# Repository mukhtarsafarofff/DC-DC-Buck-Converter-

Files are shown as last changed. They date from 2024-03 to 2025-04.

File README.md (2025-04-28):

(ENG)   A Constant Current (CC), and Constant Voltage (CV) converter can come in very handy in various conditions, for example, if you want to charge a lithium battery with a constant current you can do that very easily with this module. Furthermore, if we are testing a circuit and powering it for the first time it's always recommended to use a constant current that will limit damage to your circuit if you made any mistakes in the build process.I have two 10K potentiometers that are used to set the constant current and voltage level. Furthermore, there are three LED indicators on the board; the first one near the input connector shows when the module is in constant current mode, while the other two near the output are mainly for battery charging applications (battery charging and battery full indicators). Other than that, this IC has an input voltage range of 8V to 36V, and the output voltage of the device is 1.25V to 32V.   With max load, the PWM of the device can reach 100% duty cycle and it can operate on a 180 kHz operating frequency. The constant output current of the module is 5A and it can reach up to 96% efficiency while working. If we are talking about protection features it has thermal shutdown, short circuit protection, and current limit functionality. The main component in this board is the XL4015 buck converter IC, that is a 5pin IC designed. In the schematic we have a 78L05 Voltage Regulator which is an ultra-low-power regulator that is used to convert the input voltage to a constant 5V for the TL431 IC. The TL431 is a reference that is set to a constant current regulator mode with the help of a 71.5K resistor and a potentiometer. This reference is compared to the sense voltage from the output side of the resistor to limit the current. The circuit shown below is the TL431 circuit that is providing a constant current source to the op-amps. When the battery is fully charged, the output goes low so the charging complete LED turns on, now if a battery is charging, the other LED turns on to indicate the battery is charging. To start the test, first of all,i have connected  the buck converter module to the power supply and connect the output to the DC load, and I have set a constant load of 1A to test the circuit.

(DEU)   Ein Konstantstrom (CC)- und Konstantspannungs (CV)-Wandler können in verschiedenen Situationen äußerst nützlich sein. Wenn Sie beispielsweise eine Lithiumbatterie mit einem konstanten Strom laden möchten, können Sie dies mit diesem Modul sehr einfach tun. Darüber hinaus wird empfohlen, bei der ersten Inbetriebnahme einer Schaltung immer einen konstanten Strom zu verwenden, um Schäden an Ihrer Schaltung zu begrenzen, falls Sie während des Aufbauprozesses Fehler gemacht haben.Ich habe zwei 10K-Potentiometer, die verwendet werden, um den konstanten Strom- und Spannungspegel einzustellen. Darüber hinaus gibt es drei LED-Anzeigen auf der Platine; die erste in der Nähe des Eingangsanschlusses zeigt an, wenn das Modul im Konstantstrommodus ist, während die anderen beiden in der Nähe des Ausgangs hauptsächlich für Batterieladeanwendungen sind (Batterielade- und Batterievollanzeige). Abgesehen davon hat dieser IC einen Eingangsspannungsbereich von 8V bis 36V, und die Ausgangsspannung des Geräts beträgt 1,25V bis 32V. Bei maximaler Belastung kann das PWM des Geräts eine Tastverhältnis von 100% erreichen und es kann bei einer Betriebsfrequenz von 180 kHz arbeiten. Der konstante Ausgangsstrom des Moduls beträgt 5A und es kann bis zu 96% Effizienz erreichen, während es arbeitet. Wenn wir über Schutzfunktionen sprechen, verfügt es über thermischen Überlastschutz, Kurzschlussschutz und Funktion zur Strombegrenzung.Das Hauptkomponente auf dieser Platine ist der XL4015-Buck-Wandler-IC, ein 5-poliger IC, der entworfen wurde.Wenn wir über Schutzfunktionen sprechen, verfügt es über thermischen Überlastschutz, Kurzschlussschutz und Funktion zur Strombegrenzung. Die Hauptkomponente auf dieser Platine ist der XL4015-Buck-Wandler-IC, ein 5-poliger IC, der entworfen wurde. Im Schaltbild haben wir einen 78L05-Spannungsregler, der ein ultra-niedriger Leistungsregler ist, der verwendet wird, um die Eingangsspannung auf konstante 5V für den TL431-IC umzuwandeln. Der TL431 ist eine Referenz, die mit Hilfe eines 71,5K-Widerstands und eines Potentiometers auf den konstanten Stromreglermodus eingestellt ist. Diese Referenz wird mit der Sensorspannung von der Ausgangsseite des Widerstands verglichen, um den Strom zu begrenzen.  Die Schaltung unten ist die TL431-Schaltung, die eine konstante Stromquelle für die Operationsverstärker bereitstellt. Wenn die Batterie vollständig aufgeladen ist, wird der Ausgang niedrig, sodass die Lade-LED aufleuchtet. Wenn eine Batterie geladen wird, leuchtet die andere LED auf, um anzuzeigen, dass die Batterie geladen wird.  Ich habe zunächst das Buck-Wandler-Modul an die Stromversorgung angeschlossen und den Ausgang an die Gleichstromlast angeschlossen.

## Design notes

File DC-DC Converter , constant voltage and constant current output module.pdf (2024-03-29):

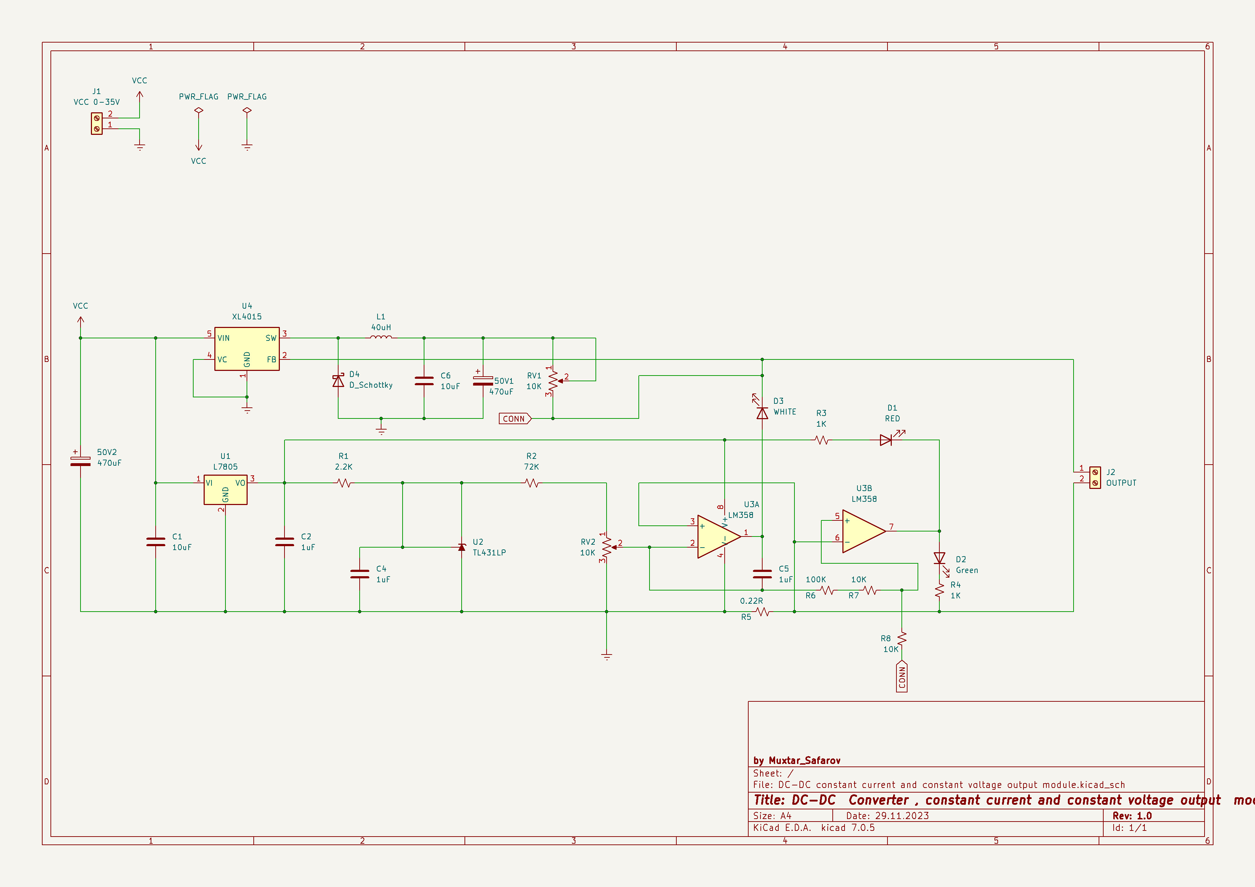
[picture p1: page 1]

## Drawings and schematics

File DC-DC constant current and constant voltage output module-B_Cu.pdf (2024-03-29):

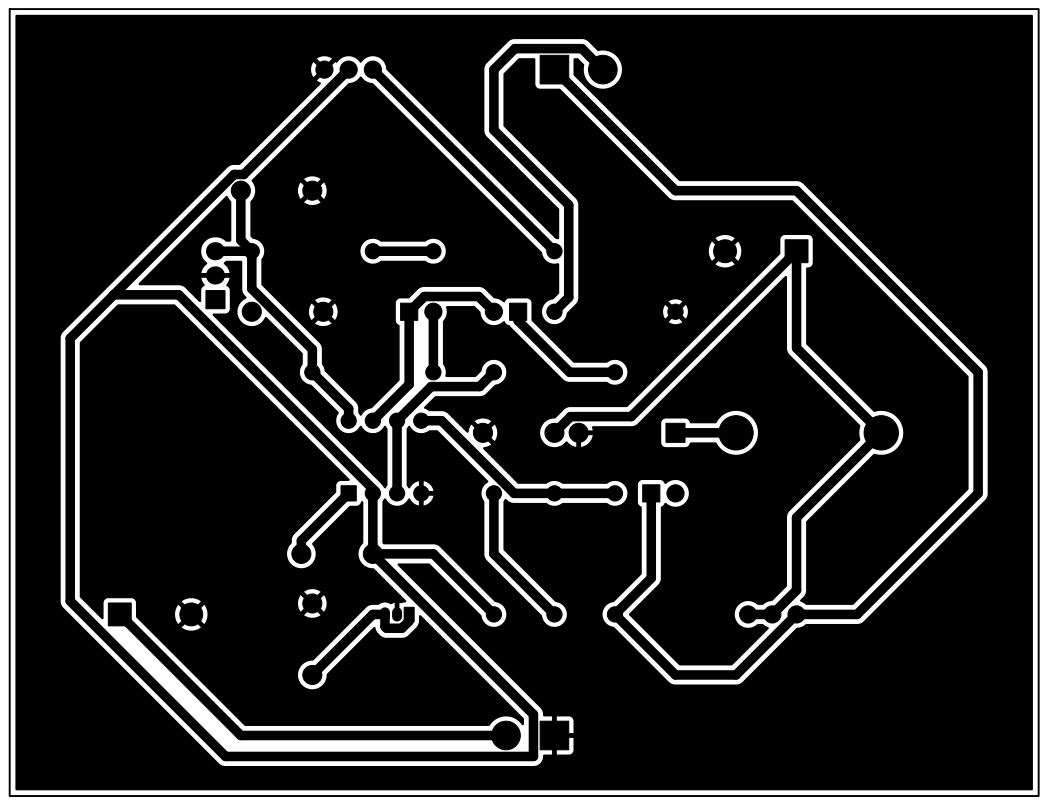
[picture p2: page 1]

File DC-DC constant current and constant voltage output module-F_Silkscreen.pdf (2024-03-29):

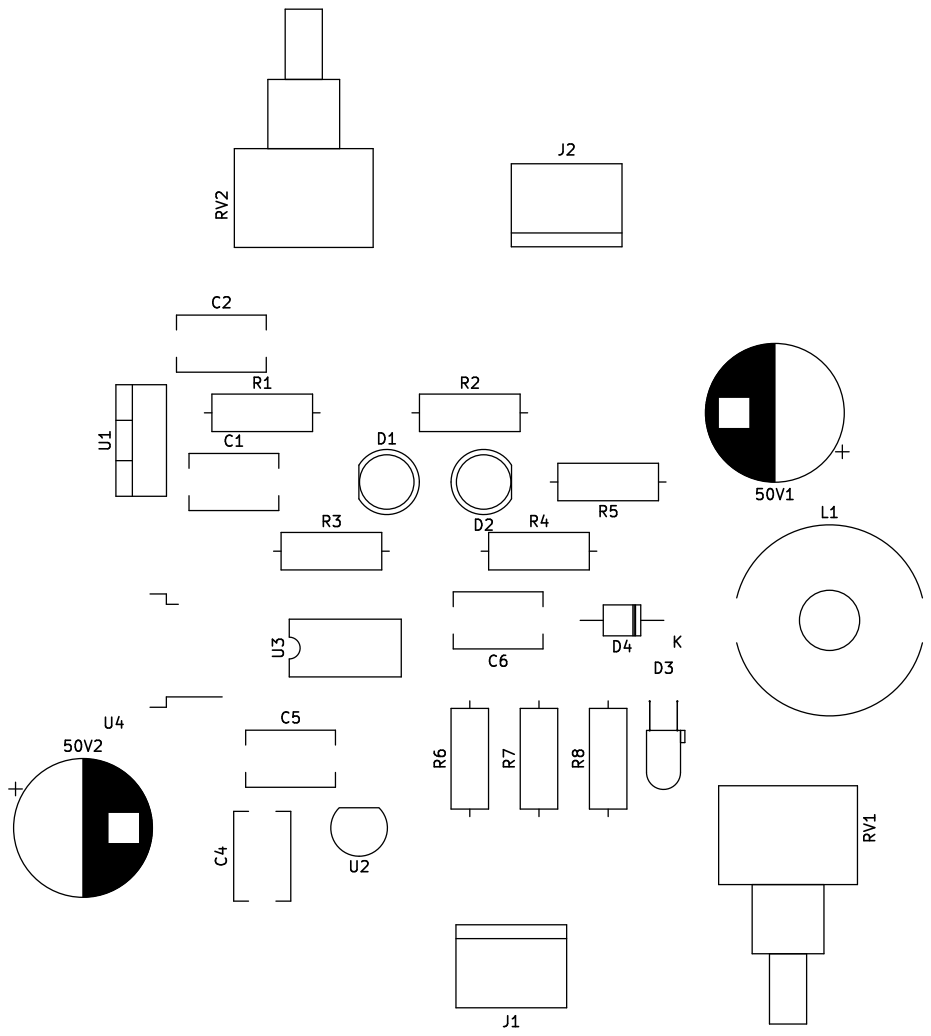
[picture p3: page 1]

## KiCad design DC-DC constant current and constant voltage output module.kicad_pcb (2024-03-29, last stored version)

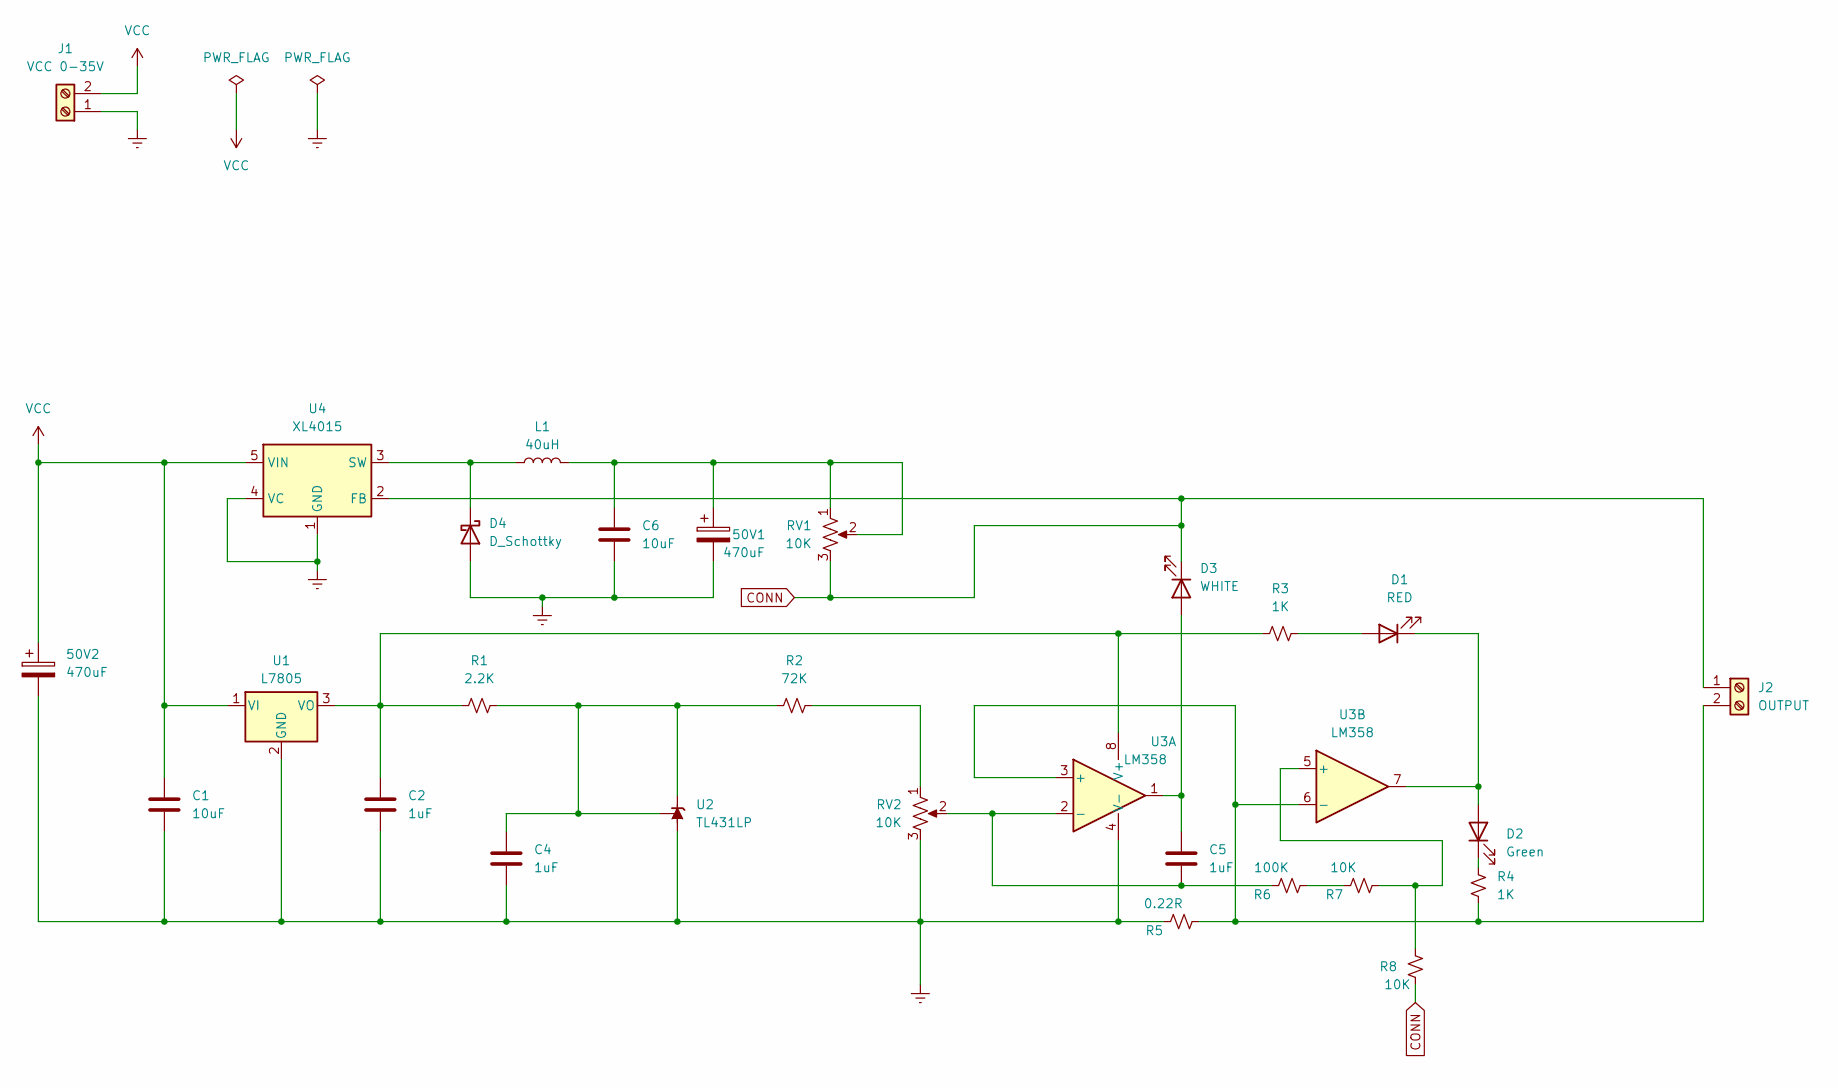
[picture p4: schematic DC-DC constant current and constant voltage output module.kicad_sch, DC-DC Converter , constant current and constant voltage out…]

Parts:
50V1, 50V2: 470uF; CP_Radial_D12.5mm_P7.50mm
C1, C6: 10uF; C_Disc_D8.0mm_W5.0mm_P7.50mm
C2, C4, C5: 1uF; C_Disc_D8.0mm_W5.0mm_P7.50mm
D1: RED; LED_D5.0mm
D2: Green; LED_D5.0mm_Clear
D3: WHITE; LED_D3.0mm_Horizontal_O3.81mm_Z6.0mm
D4: D_Schottky; D_T-1_P10.16mm_Horizontal
J1: VCC 0-35V; TerminalBlock_bornier-2_P5.08mm
J2: OUTPUT; TerminalBlock_bornier-2_P5.08mm
L1: 40uH; L_Toroid_Horizontal_D17.3mm_P15.24mm_Bourns_2000
R1: 2.2K; R_Axial_DIN0309_L9.0mm_D3.2mm_P12.70mm_Horizontal
R2: 72K; R_Axial_DIN0309_L9.0mm_D3.2mm_P12.70mm_Horizontal
R3, R4: 1K; R_Axial_DIN0309_L9.0mm_D3.2mm_P12.70mm_Horizontal
R5: 0.22R; R_Axial_DIN0309_L9.0mm_D3.2mm_P12.70mm_Horizontal
R6: 100K; R_Axial_DIN0309_L9.0mm_D3.2mm_P12.70mm_Horizontal
R7, R8: 10K; R_Axial_DIN0309_L9.0mm_D3.2mm_P12.70mm_Horizontal
RV1, RV2: 10K; Potentiometer_Vishay_148-149_Single_Horizontal
U1: L7805; TO-220-3_Vertical
U2: TL431LP; TO-92_Inline
U3: LM358; DIP-8-16_W7.62mm
U4: XL4015; TO-263-5_TabPin3

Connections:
CONN: D3.1 (K), J2.1, R8.1, RV1.3, U4.2 (FB)
Earth: 50V1.2, 50V2.2, C1.2, C2.2, C4.2, C6.2, D4.2 (A), J1.1, R5.1, RV2.3, U1.2 (GND), U2.2 (A), U3.4 (V-), U4.1 (GND), U4.4 (VC)
unnamed: 50V1.1, C6.1, L1.2, RV1.1, RV1.2
unnamed: D1.2 (A), R3.2
unnamed: D1.1 (K), D2.2 (A), U3.7
unnamed: D2.1 (K), R4.2
unnamed: C5.1, D3.2 (A), U3.1
unnamed: D4.1 (K), L1.1, U4.3 (SW)
unnamed: J2.2, R4.1, R5.2, U3.3 (+), U3.6 (-)
unnamed: R2.2, RV2.1
unnamed: R6.2, R7.1
unnamed: C2.1, R1.1, R3.1, U1.3 (VO), U3.8 (V+)
unnamed: C4.1, R1.2, R2.1, U2.1 (REF), U2.3 (K)
unnamed: C5.2, R6.1, RV2.2, U3.2 (-)
unnamed: R7.2, R8.2, U3.5 (+)
VCC: 50V2.1, C1.1, J1.2, U1.1 (VI), U4.5 (VIN)

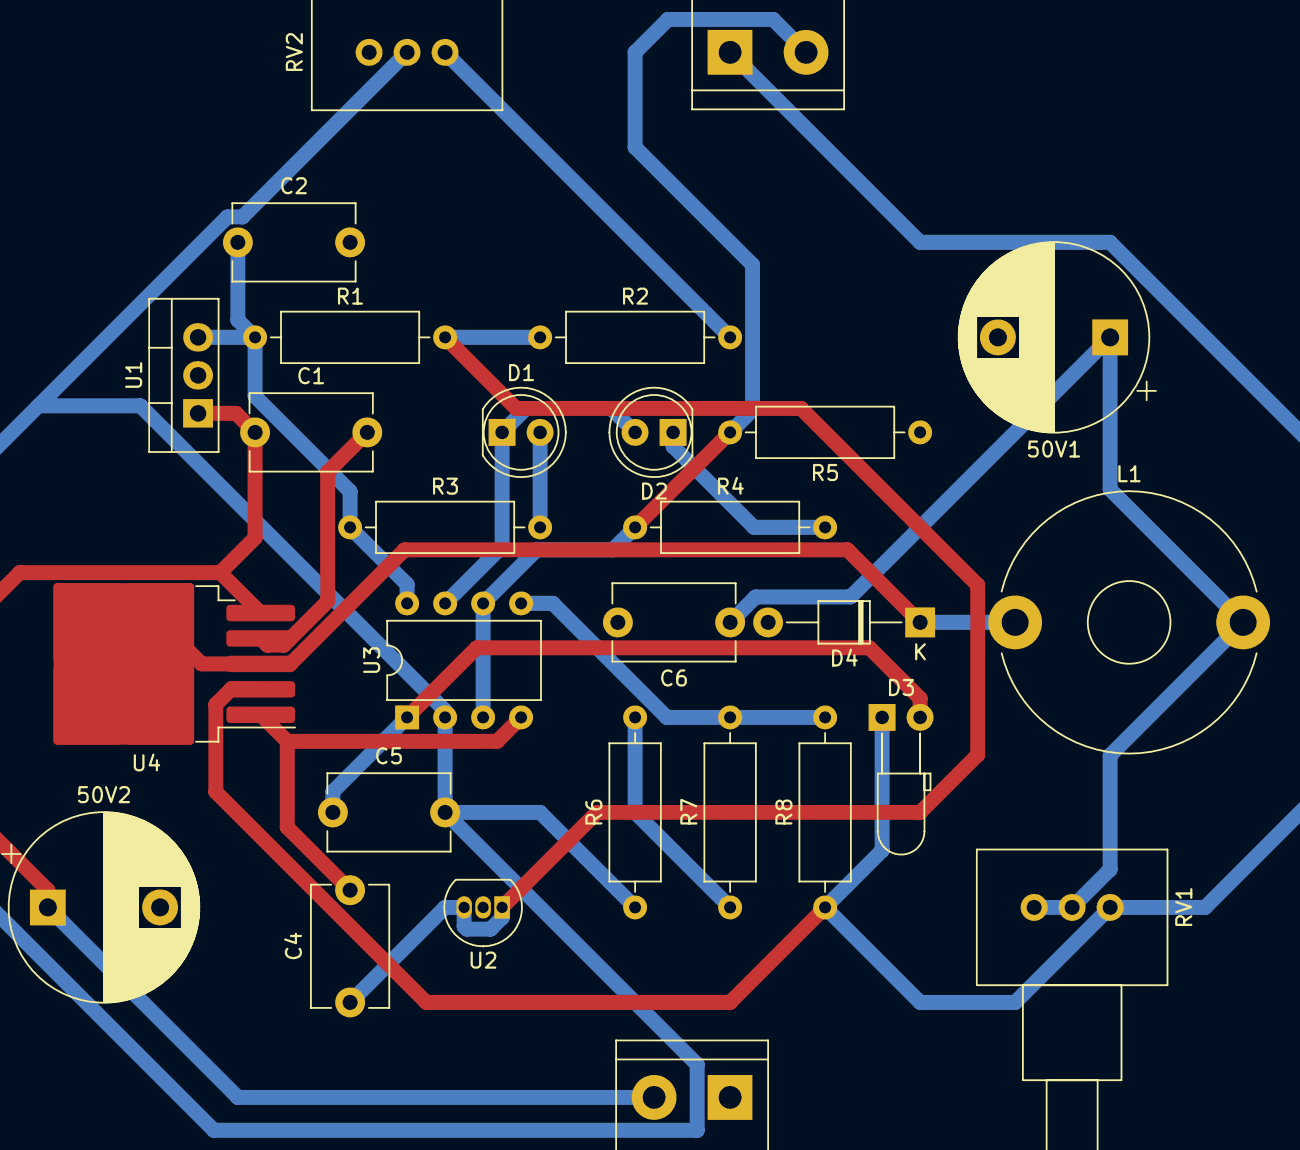
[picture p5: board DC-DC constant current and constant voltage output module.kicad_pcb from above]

Board: 2 copper layers, 28 parts (0 on the bottom side), 16 nets.
